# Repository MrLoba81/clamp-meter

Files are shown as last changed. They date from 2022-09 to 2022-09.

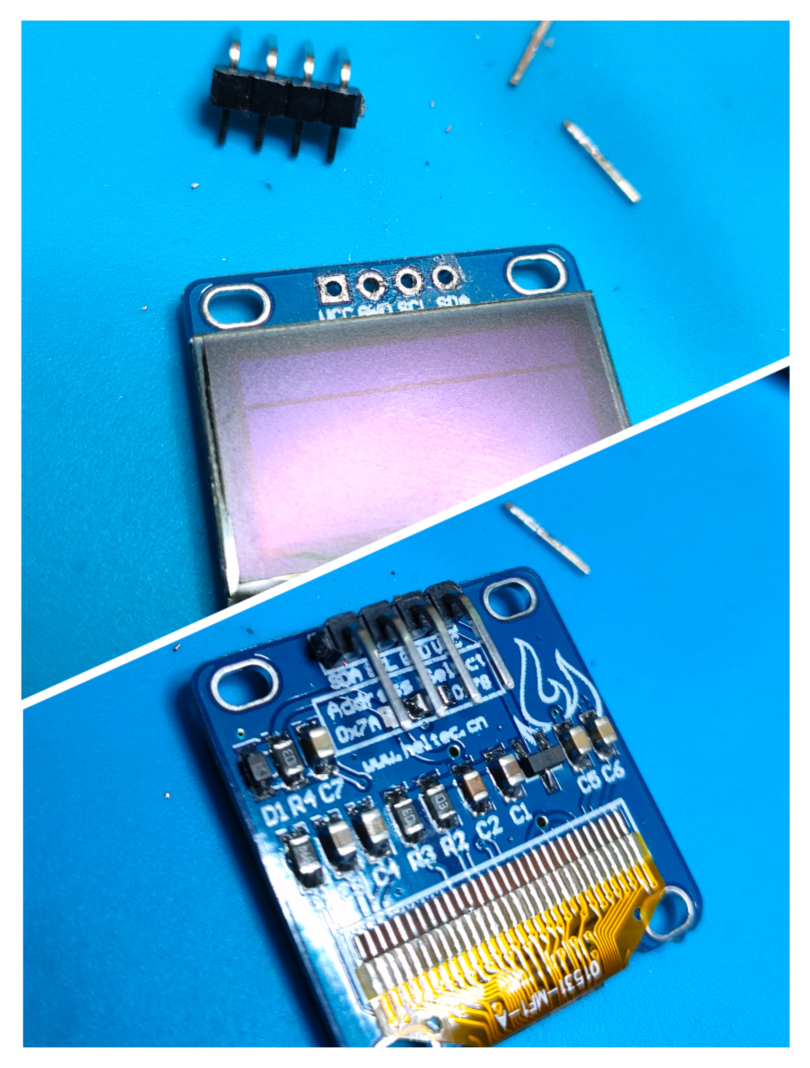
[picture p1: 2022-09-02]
images/display.jpg

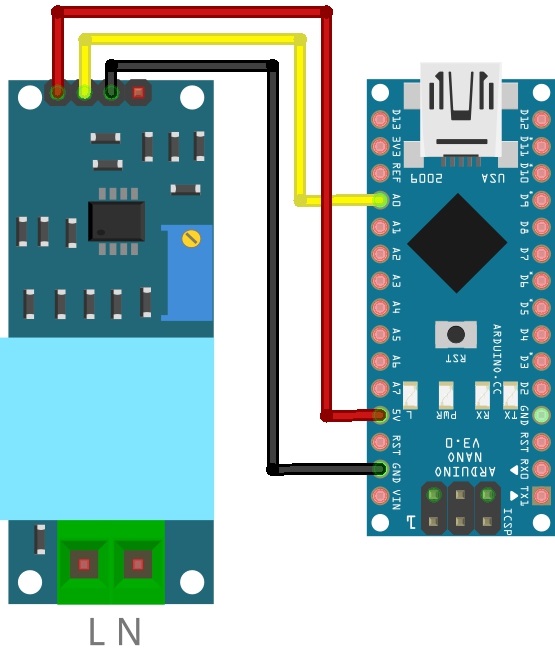
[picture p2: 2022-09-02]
images/ZMPT101B.jpg

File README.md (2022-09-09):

# Clamp Meter
A simple, non invasive powermeter based on Arduino Nano/Every using the library [EmonLib](https://www.arduino.cc/reference/en/libraries/emonlib/) from [OpenEnergyMonitor](https://learn.openenergymonitor.org/)  
Some nice pics [here](https://www.instagram.com/p/CiNQrXfMGJH/)

### Part list
* [SCT013 20A-1V](https://www.poweruc.pl/collections/split-core-current-transformers2/products/split-core-current-transformer-sct013-rated-input-5a-100a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)
* [ZMPT101B](https://www.amazon.it/ANGEEK-ZMPT101B-Voltage-Transformer-Arduino/dp/B07ZDJS7CD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)
* [Arduino Nano](https://www.amazon.it/AZDelivery-Atmega328-compatibile-Arduino-CH340/dp/B01LWSJBTD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)
* [SSD1306 single color](https://www.amazon.it/AZDelivery-Display-retroilluminato-Raspberry-gratuito/dp/B01L9GC470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) or [SSD1306 yellow/blue](https://www.amazon.it/ARCELI-pollici-SSD1306-auto-luminoso-Raspberry/dp/B07J2QWF43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)
* [Power Switch](https://it.aliexpress.com/item/32813951635.html?spm=a2g0o.order_list.0.0.21ef3696thxWUk&gatewayAdapt=glo2ita) - 8.8mm X 13.3mm
* [Fuse Holder](https://www.ebay.it/itm/291730713153)
* [IEC-320-C8](https://www.ebay.it/itm/254880092205)
* [Perfboard 5x7cm](https://www.amazon.it/AZDelivery-Prototipo-Breadboard-Circuit-progetti/dp/B078HV79XX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)
* [3,5mm pcb female audio jack](https://www.ebay.it/itm/201058258889)
* [AC/DC 5v 700mA](https://www.ebay.it/itm/332431319967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)
* [Pin Header 90°](https://www.amazon.it/Aussel-2-54mm-Breakable-Connector-Arduino/dp/B01MDRPUFU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)
* 2x 10KOhm resistors
* 1x 104 ceramic capacitor
* 1x 10uf electrolitic capacitor
* [1x Male and Female 2pin JST connector](https://www.amazon.it/CQRobot-Pieces-2-54mm-JST-XHR-Connector/dp/B01EQGNZ2I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)
* [1x Male and Female 3pin JST connector](https://www.amazon.it/CQRobot-Pieces-2-54mm-JST-XHR-Connector/dp/B01EQGNZ2I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)
* [1x Male and Female 4pin JST connector](https://www.amazon.it/CQRobot-Pieces-2-54mm-JST-XHR-Connector/dp/B01EQGNZ2I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)
* [2x Dupont 4pins](https://www.ebay.it/itm/231161797482?hash=item35d2511b6a:g:voEAAOxyj4hTIHg2)
* [7x Female Dupont to crimp](https://www.ebay.it/itm/331155852325?hash=item4d1a6d4c25:g:KLQAAOSwzhVWq8K8)
* 2x M3 nuts
* 2x 12mm M3 screws

### Assembly
The PCB is really simple, you can find the schematic [here](https://github.com/MrLoba81/clamp-meter/blob/main/schematic/ClampMeter_schema.jpg)  
My final result is on my [instagram profile](https://www.instagram.com/mrloba81/) in this [post](https://www.instagram.com/p/Ch1pz97Maak/)

#### Modify the pin header of the SSD1306
I desoldered the classic pin header from the display and soldered the 90° version, due to have less space requirements  
You che have a look [here](https://github.com/MrLoba81/clamp-meter/blob/main/images/display.jpg)

#### The enclosure
You can find two stl [here](https://github.com/MrLoba81/clamp-meter/tree/main/enclosure)  
It's suggested to use a Layer height of 0.2mm and First layer of 0.2mm Infill 12%  
I printed it with the classic PLA

### Tune the ZMPT101B
Pay attention while performing this task due to High Alternate Voltage!!!

Connect the module as shown [here](https://github.com/MrLoba81/clamp-meter/blob/main/images/ZMPT101B.jpg)

You can open the Serial Plotter of the Arduino IDE and upload the following sketch to check if the syne wave is complete.
```
void setup() {  
  Serial.begin(9600);
}

void loop() {
  Serial.println(analogRead(A0));

  delay(100);
}
```
If not, ex. the waveform is cut from the top or bottom, you have to turn the potentiometer on the module to display the full waveform otherwise you'll get incorrect measurement.  
A bad wawe [here](https://github.com/MrLoba81/clamp-meter/blob/main/images/ZMPT-BadWawe.PNG)  
A good wawe [here](https://github.com/MrLoba81/clamp-meter/blob/main/images/ZMPT-GoodWawe.PNG)  
Have also a look at my old [post](https://www.instagram.com/p/CN0LfA8lw_c/)  

### The Firmware
Firmware is really simple, it depends on the followind libraries
* openenergymonitor/EmonLib@^1.1.0
*	adafruit/Adafruit SSD1306@^2.5.7
    * This will also install dependencies
        * Adafruit BusIO
        *	Adafruit GFX Library

[Here](https://github.com/MrLoba81/clamp-meter/tree/main/firmware) you can find the PlatformIO project

You need to adjust two *constants* in order to have correct measurements
```
#define VOLTAGE_CALIBRATION 260
#define CURRENT_CALIBRATION 19
```
Use your multimeter, in Voltage and Current mode, to fine tune the two values  
You can find a lot of informations on calibration and other questions on the [Open EnergyMonitor](https://learn.openenergymonitor.org/electricity-monitoring/ctac/calibration) website  
Clarifications about [ADC resolution limits](https://learn.openenergymonitor.org/electricity-monitoring/ct-sensors/measurement-implications-of-adc-resolution-at-low-current-values)

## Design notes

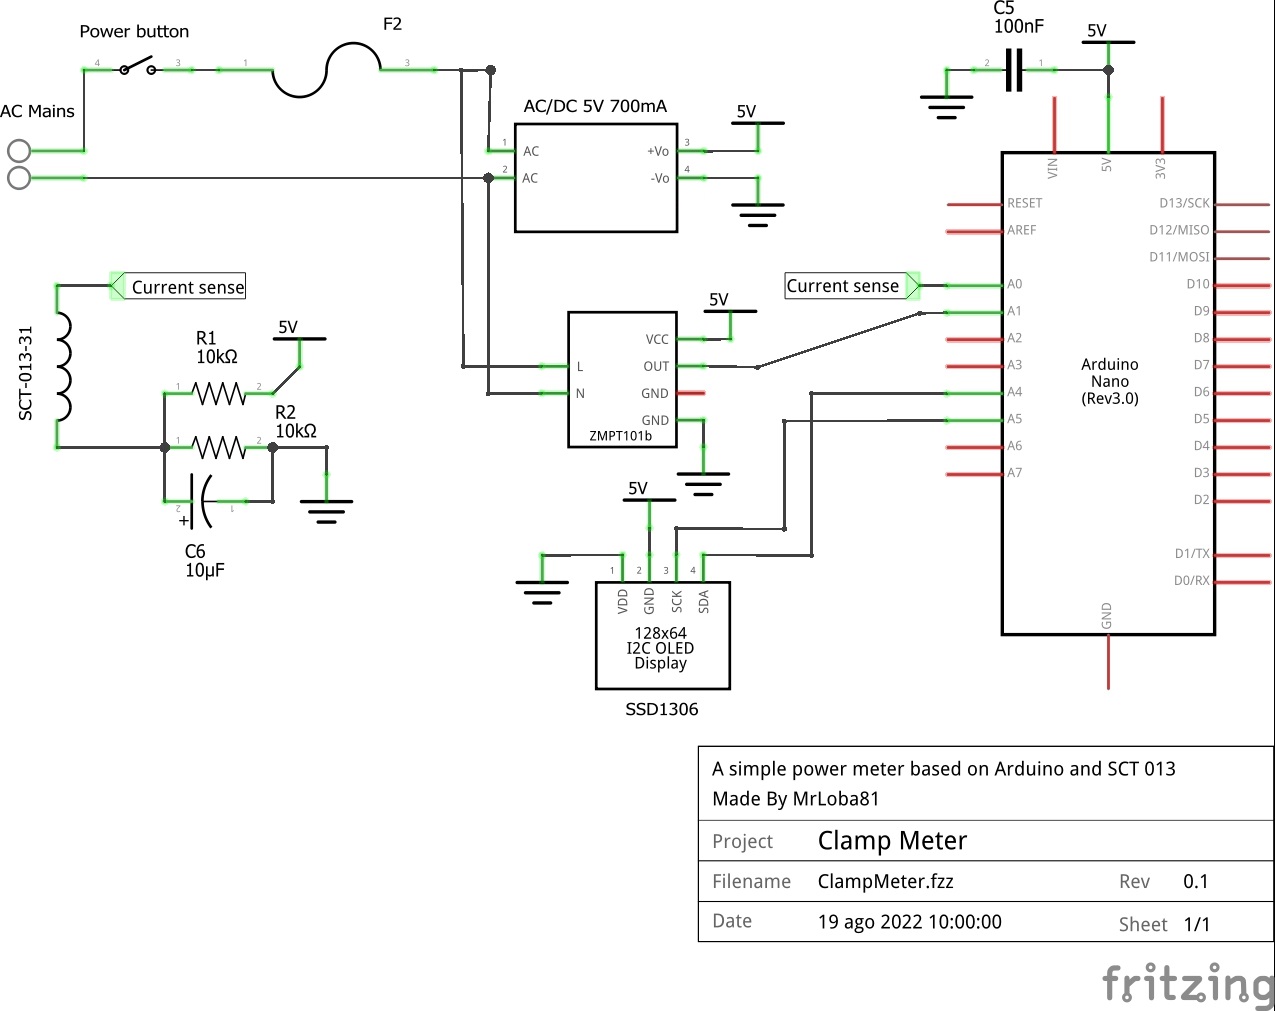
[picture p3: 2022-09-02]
schematic/ClampMeter_schema.jpg

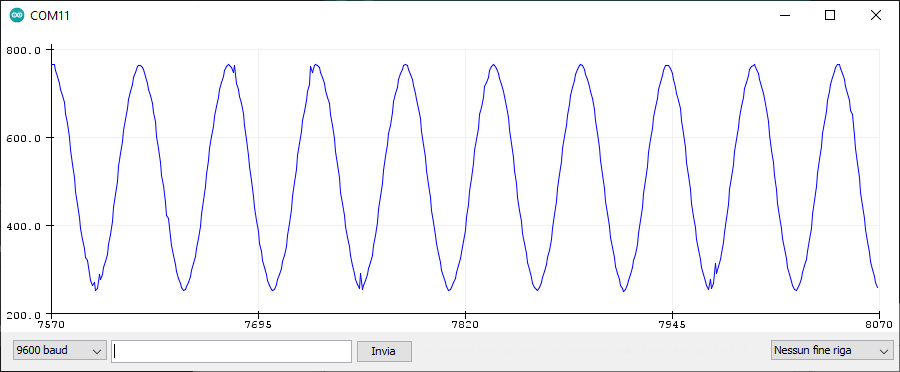
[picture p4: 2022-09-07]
images/ZMPT-GoodWawe.PNG

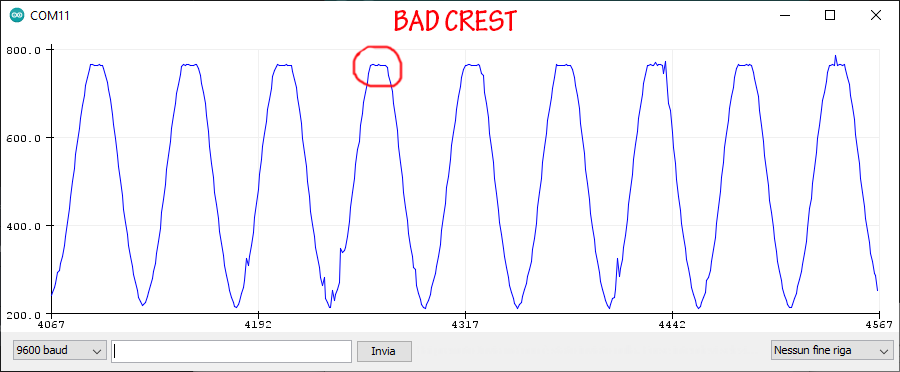
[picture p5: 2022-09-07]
images/ZMPT-BadWawe.PNG

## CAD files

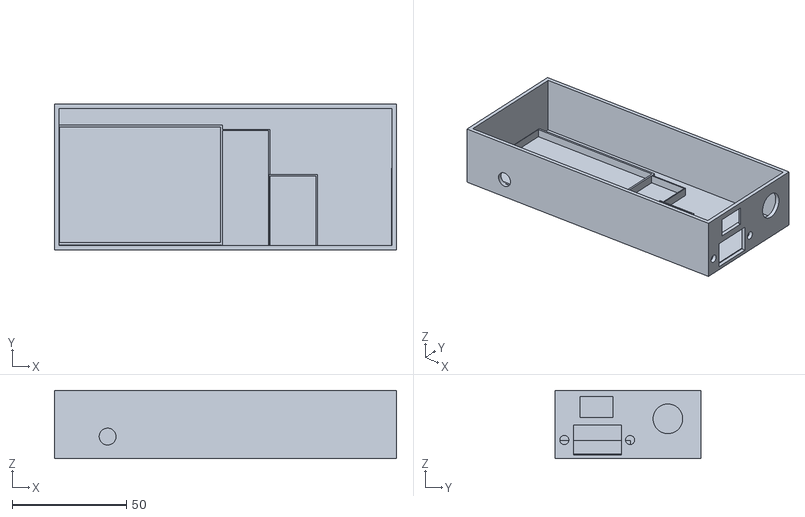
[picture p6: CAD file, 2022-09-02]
enclosure/ClampMeterBox.stl
150.0 x 64.0 x 30.0

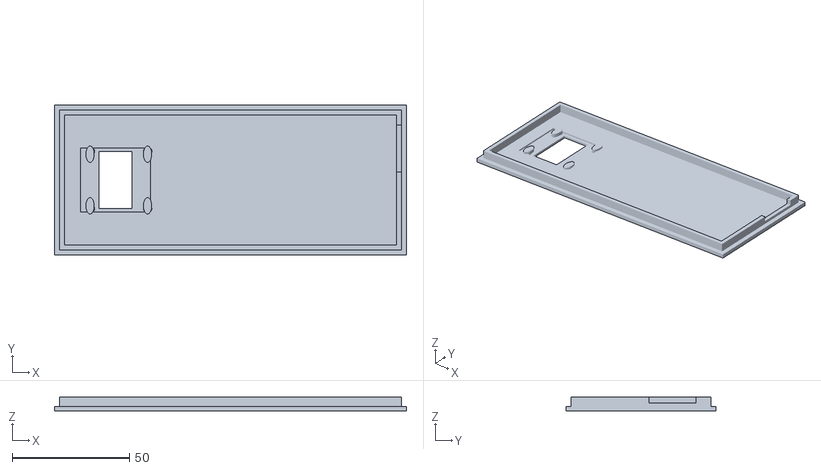
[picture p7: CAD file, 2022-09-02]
enclosure/ClampMeterCover.stl
150.0 x 64.0 x 6.00

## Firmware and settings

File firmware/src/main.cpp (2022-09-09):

#include <Arduino.h>
#include <EmonLib.h>
#include <SPI.h>
#include <Wire.h>
#include <Adafruit_GFX.h>
#include <Adafruit_SSD1306.h>
#include <Fonts/FreeMono9pt7b.h>
#include <Fonts/FreeMonoBold12pt7b.h>

#define SCREEN_WIDTH 128
#define SCREEN_HEIGHT 64
#define OLED_RESET -1
#define SCREEN_I2C_ADDRESS 0x3C

// To be adjusted to fine tune your measurements
// use yout multimeter in Voltage and Current mode to find the ridght value
#define VOLTAGE_CALIBRATION 260
#define CURRENT_CALIBRATION 19

Adafruit_SSD1306 display(SCREEN_WIDTH, SCREEN_HEIGHT, &Wire, OLED_RESET);
EnergyMonitor emon;

double watt, realWatt;

void draw();
void printHCentered(const char *buffer, int16_t y);

void setup()
{
  Serial.begin(9600);
  while (!Serial)
  {
  }
  Serial.println("Setup the device");

  // For 12BIT ADC Resolution analogReadResolution(ADC_BITS);

  emon.voltage(A1, VOLTAGE_CALIBRATION, 1.7);
  emon.current(A0, CURRENT_CALIBRATION);

  if (!display.begin(SSD1306_SWITCHCAPVCC, SCREEN_I2C_ADDRESS))
  {
    Serial.println("SSD1306 allocation failed");
    delay(1000);
    abort();
  }

  // Print the header
  display.clearDisplay();
  display.setFont(&FreeMono9pt7b);
  display.setTextSize(1);
  display.setTextColor(SSD1306_BLACK);
  display.fillRect(0, 0, 127, 16, SSD1306_WHITE);
  printHCentered("Clamp Meter", 11);
  // Draw the info box and set the fonts
  display.drawRect(0, 17, 127, 47, SSD1306_WHITE);
  display.setTextColor(SSD1306_WHITE);
  display.setFont();
  // Print the Author
  printHCentered("Made by", 20);
  display.setFont(&FreeMonoBold12pt7b);
  printHCentered("MrLoba81", 45);
  display.setFont();
  printHCentered("instagram/mrloba81", 52);
  display.display();

  delay(2000);

  Serial.println("End Setup");
}

void loop()
{
  emon.calcVI(60, 2000);
  /* Serial.print("CalcVI: ");
  emon.serialprint(); */

  watt = emon.apparentPower;
  realWatt = emon.realPower;

  draw();
}

void draw()
{
  char buffer[19];
  char doubleBuffOne[8];
  char doubleBuffTwo[8];

  // Clear information box
  display.fillRect(1, 18, 125, 45, SSD1306_BLACK);

  dtostrf(emon.Irms, 5, 2, doubleBuffOne);
  dtostrf(emon.powerFactor, 5, 2, doubleBuffTwo);
  sprintf(buffer, "A:%s PF:%s", doubleBuffOne, doubleBuffTwo);
  printHCentered(buffer, 24);

  const char *strToPrint;
  if (watt >= 1000.0)
  {
    strToPrint = "K:";
    watt = watt / 1000.0;
    realWatt = realWatt / 1000.0;
  }
  else
  {
    strToPrint = "W:";
  }

  dtostrf(realWatt, 5, 2, doubleBuffOne);
  dtostrf(watt, 5, 2, doubleBuffTwo);
  sprintf(buffer, "%s%s ap:%s", strToPrint, doubleBuffOne, doubleBuffTwo);
  printHCentered(buffer, 38);

  dtostrf(emon.Vrms, 5, 2, doubleBuffOne);
  sprintf(buffer, "V: %s", doubleBuffOne);
  printHCentered(buffer, 52);

  display.display();
}

void printHCentered(const char *buffer, int16_t y)
{
  int16_t x1, y1;
  uint16_t w, h;
  display.getTextBounds(buffer, 0, y, &x1, &y1, &w, &h);
  int16_t x = ((SCREEN_WIDTH - 2) / 2) - (w / 2);
  display.setCursor(x, y);
  display.print(buffer);
}

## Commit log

2022-09-02 Enclosure, Schema and Display mod
    [ClampMeterBox.stl, ClampMeterCover.stl]
2022-09-07 zmpt calibration wawe
